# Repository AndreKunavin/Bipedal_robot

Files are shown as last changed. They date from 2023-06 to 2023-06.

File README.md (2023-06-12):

# Бипедальный робот

Проект по курсу "Проектирование, прототипирование и производство в проектном формате"

Данная работа посвящена построению двуногого робота, способного удерживать равновесие и шагать. Проект несёт образовательный характер для нашей команды: понимание проблем, возникающих при разработке подобных устройств, а также самостоятельное их решение - цель нашего проекта.

Описание проекта можно посмотреть в файле "bipedal.pdf"	

## Технические заметки и исходные файлы для печати
В папке STL&SLDPTR находятся файлы с 3D моделями основных компонент робота. Далее приведено их краткое описание. 

С целью упрощения управления прототипами, а также более эффективного распределения сил команды, было решено разделить проект на две части: 
### 1) Разработка "активного" голеностопа
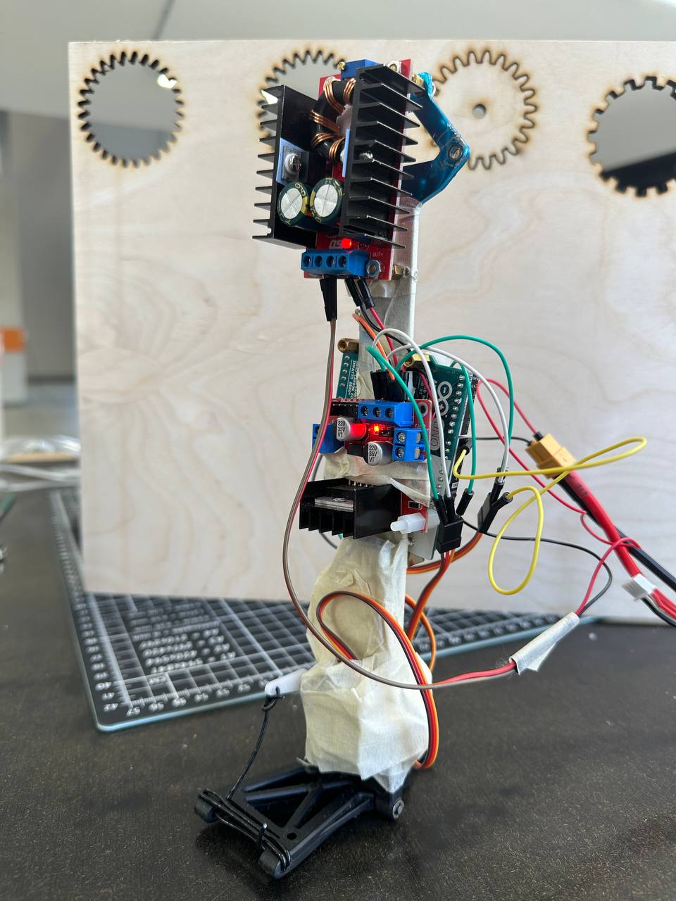
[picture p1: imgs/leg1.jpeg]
Голеностоп


Гироскоп, установленный свехру, реагирует на внешнее механическое воздействие и подает сигнал на стопу, которая пытается скомпенсировать воздействие.
  
### 2) Разработка основной механической конструкции робота
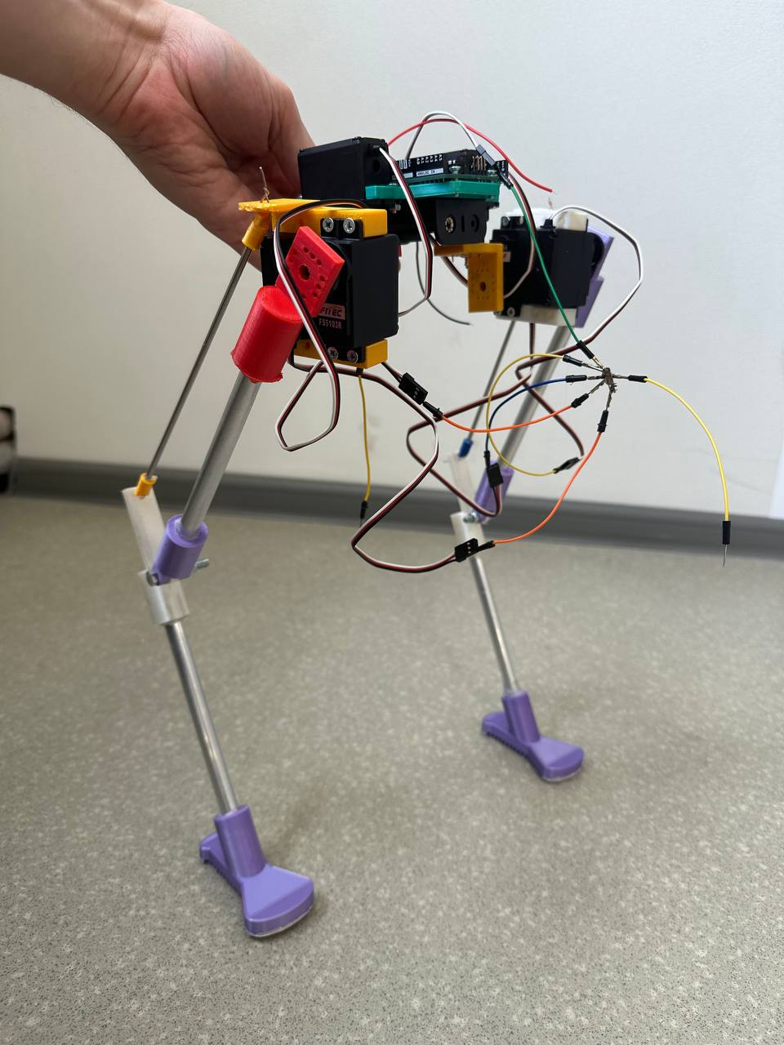
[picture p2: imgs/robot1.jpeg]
Основная механическая часть
 

1. БлокСерво.STL и БлокСерво2.STL - крепление двух сервоприводов к платформе с Arduino. Один из сервоприводов отвечает за поднятие стопы (меняет относительное положение верхней трубки и спицы), а второй - за вынос ноги вперед как целого.
2. ВерхнееКрепление.STL, Нижнее крепление.STL - крепления, соединяющие нижнюю и верхнюю трубки. Нижнее крепление имеет рычаг, к которому крепится спица
3. НогаПривод.STL - соединение верхней трубки ноги и сервопривода, отвечающего за поднятие стопы
4. Стопа.STL - "пассивная" стопа, временная альтернатива вышеописанной стопе
5. КреплениеДляПлаты.STL - крепление, на котором размещается "мозг" робота - Arduino Uno

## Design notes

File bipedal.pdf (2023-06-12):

Министерство образования и науки Российской Федерации Московский физико-технический институт (национальный исследовательский университет)

Физтех-школа Радиотехники и Компьютерных Технологий (ФРКТ) Дисциплина «Проектирование, прототипирование и производство в проектном формате»

ПОЯСНИТЕЛЬНАЯ ЗАПИСКА К КУРСОВОМУ ПРОЕКТУ «БИПЕДАЛЬНЫЙ РОБОТ»

Выполнили:
Бексултанова Айкун, Б01-906

Кофанов Даниил, Б01-909

Кунавин Андрей, Б01-903

Фёдоров Михаил, Б01-905

Долгопрудный, 2023

### 1. Разработчики

- Бексултанова Айкун: обзор статей, печать деталей, подготовка презентации, сборка.
- Кофанов Даниил: прототипирование активного голеностопа, CAD-моделирование монтажной платформы.
- Кунавин Андрей: обработка деталей после печати, сборка.
- Фёдоров Михаил: CAD-моделирование конечностей, сборка

### 2. Цель работы

Осуществить попытку в построении двуногого робота в ограниченном бюджете, способного удерживать равновесие и шагать, понять проблемы возникающие при разработке подобных устройств и попытаться решить их самостоятельно. В виду этого, данный проект разрабатывался со стремлением к минимизации заимствования из уже существующих решений.

Основной идеей нашей модели является разделение механических узлов на две части, одна из которых ответственна только за удержание/вывод из положения равновесия, а другая служит для непосредственного выноса/возвращения конечности при шаге. Такая модель должна упростить разработку в силу минимизации интерференции в управлении этими механическими узлами, позволяя разбить это управление на 2 сабрутины. В виду этого, разработка разделилась на 2 соответствующих подпроекта.

A. Модель продольной устойчивости.

Достижение устойчивости достигается за счёт управления стопой (см. Рисунок 1). В момент выхода из положения равновесия (т.е. детектирования гироскопом ускорения) модель стремится нивелировать внешнее воздействие с помощью сервоприводов, создавая компенсирующий момент.

Стоит отметить, что отдельное изготовление этого устройства было необходимо для

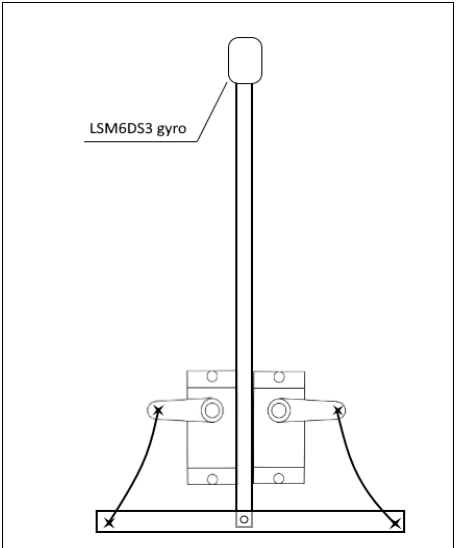
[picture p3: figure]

проверки самой идеи удержания равновесия с помощью лишь стопы (т.е. при неизменной геометрии остальной части). В конечной имплементации система управления и питания так же бы были вынесены в общий корпус, поэтому внешнему виду, качеству исполнения и монтажу уделялось мало внимания.

Рисунок 1: Схема модуля устойчивости

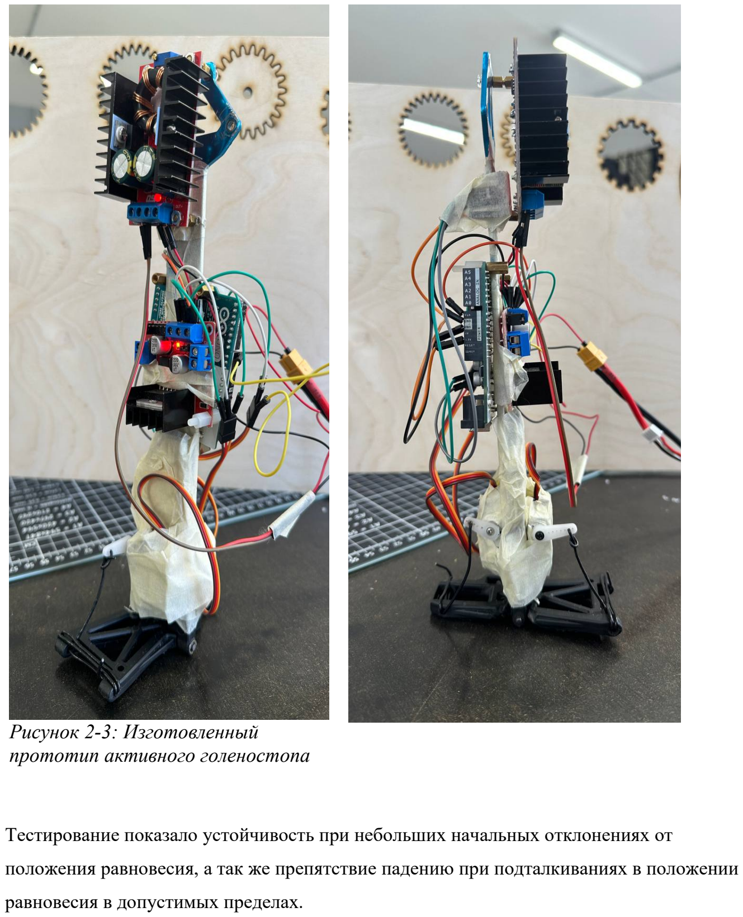
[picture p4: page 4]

Тестирование показало устойчивость при небольших начальных отклонениях от положения равновесия, а так же препятствие падению при подталкиваниях в положении равновесия в допустимых пределах.

Рисунок 2-3: Изготовленный
прототип активного голеностопа

B. Основная механическая часть

Основная механическая часть (см. Рисунок 4) управляется 6 сервоприводами, по 3 на каждую конечность. В каждой ноге, 2 сервопривода обеспечивают поворот ноги относительно корпуса в вертикальной плоскости, необходимого для осуществления шага, и горизонтальной плоскости, необходимого для поворота. Третий сервопривод воздействуя на рычаг обеспечивает сгибание ноги, что необходимо для управления высотой робота и обеспечения меньшего углового момента относительно стопы, что позволяет активному голеностопу лучше справляться с удержанием равновесия.

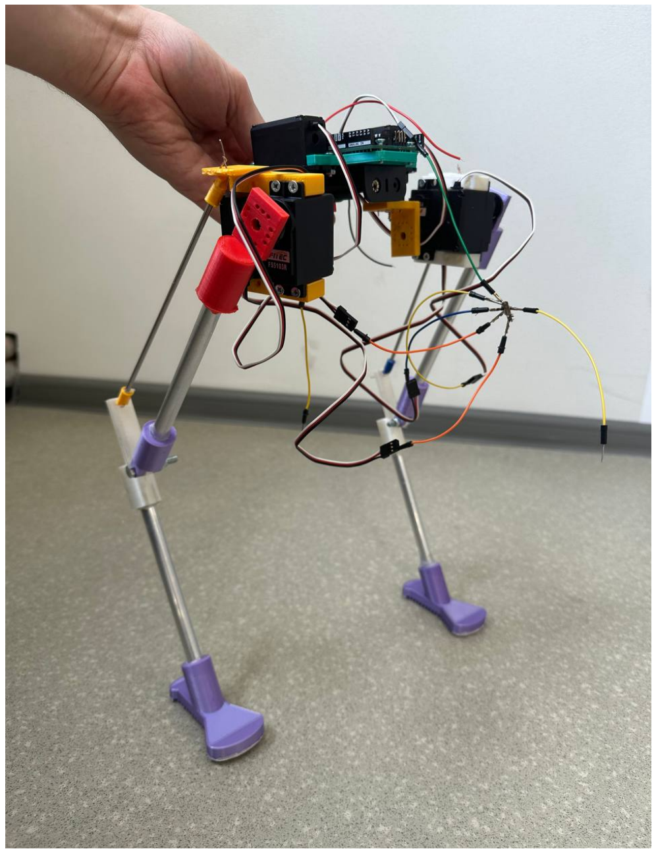
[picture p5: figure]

Рисунок 4: Основная механическая часть

В данной реализации стопа является монолитной. Предполагается, что после обеспечения робота адекватной системой питания и базового управления сервоприводами (хотя бы обеспечения статического положения), следует заменить её на подвижную стопу, аналогичную изображённой на Рисунке 1 и крепящуюся на стержень голени, гироскоп же установить в верхней точке робота.

### 3. Обзор существующих аналогов

Наиболее близким к данному проекту является робот описанный в статье https://www.mdpi.com/2076-0825/11/3/75/htm. Одним из главных отличий является использования в нём особых бесколлекторных двигателей, в то время как мы используем более дешёвые и общие сервоприводы. Принципиально что сервоприводы качественно отличаются от двигателей в том смысле что двигатели могут свободно вращаться под действием внешних сил, в то время как сервопривод всегда стремится удержать определённое положение. Это создаёт трудности при жёстком соединении сервоприводов со стопой в момент постановки стопы в процессе переступания. В виду этого в нашей реализации стопа соединяется с сервоприводами не стержнем, а тросом, допуская тем самым «расслабление» (т.е. свободное позиционирование) стопы при необходимости.

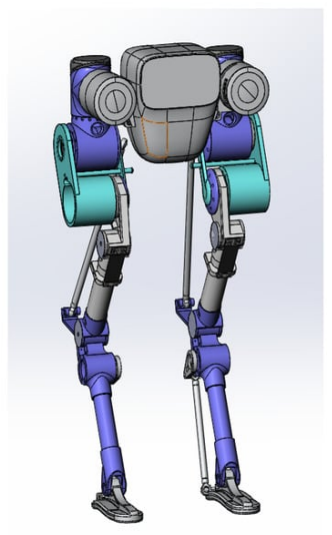
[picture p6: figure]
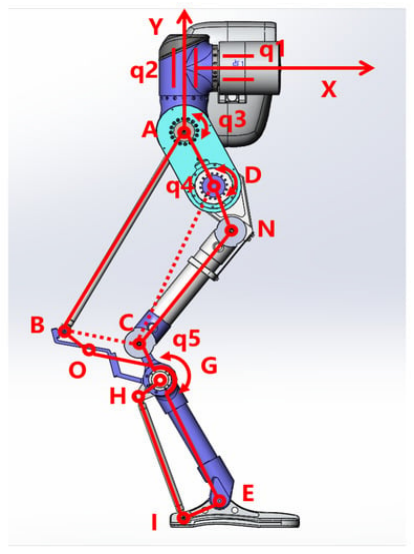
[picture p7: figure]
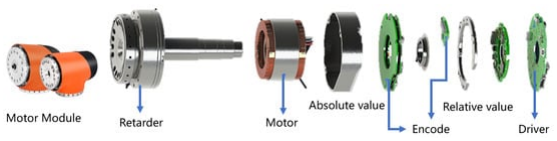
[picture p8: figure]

Рисунок 7: Составные части двигателя робота из статьи

Рисунок 5-6: 3D модель
робота из статьи

### 4. Процесс проектирования и изготовления

Проектирование состояло из следующих шагов:
1) Обзор уже существующих роботов и выбор механической модели;
2) Подбор необходимых электронных компонентов (гироскопа, плат управления питанием, сервоприводы и т.д.);
3) Прототипирование и тестирование активного голеностопа.
4) Проектирование и изготовление механической части;
5) Сборка механической части, подключение электронных компонент;
6) Интеграция активного голеностопа в основную механическую часть;
7) Обеспечение устойчивости путём калибровки и отладки параметров (границ ускорений для начала управления сервоприводами, скорости поворота сервоприводов и т. д.);
8) Имплементация механизма шагания путём контролируемого выхода из положения равновесия, выставления одной из ног вперёд и возвращения в исходное положение.

### 5. Достигнутые результаты и предстоящие цели

К сожалению, полностью работу выполнить не удалось, был достигнут только 5 пункт. В дальнейшей работе помимо перечисленных выше пунктов 6-8 остаётся открытым вопрос поперечной устойчивости в момент удержания равновесия на одной стопе. Одним из возможных решений (помимо продолжения ширины стопы до центра тяжести) является добавление в стопу степени свободы и организация механизма аналогичного механизму удержания продольного равновесия.

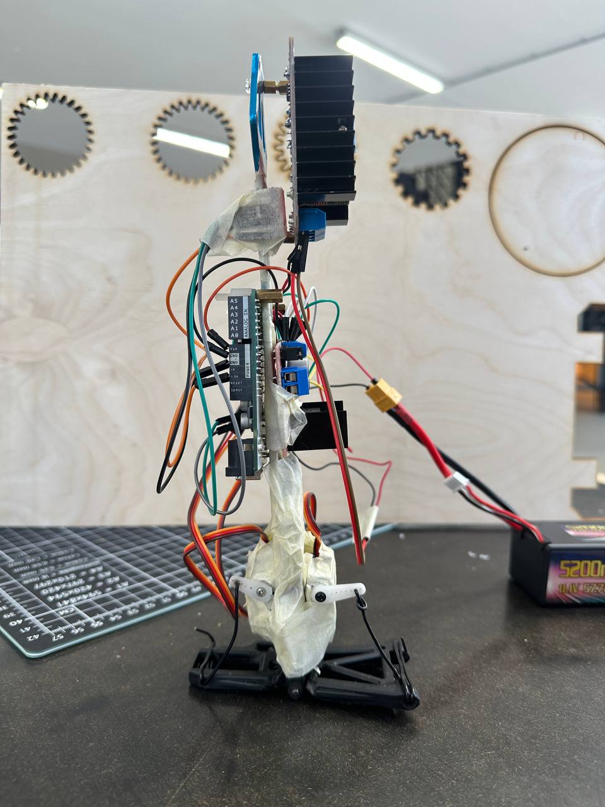
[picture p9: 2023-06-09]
imgs/leg3.jpeg

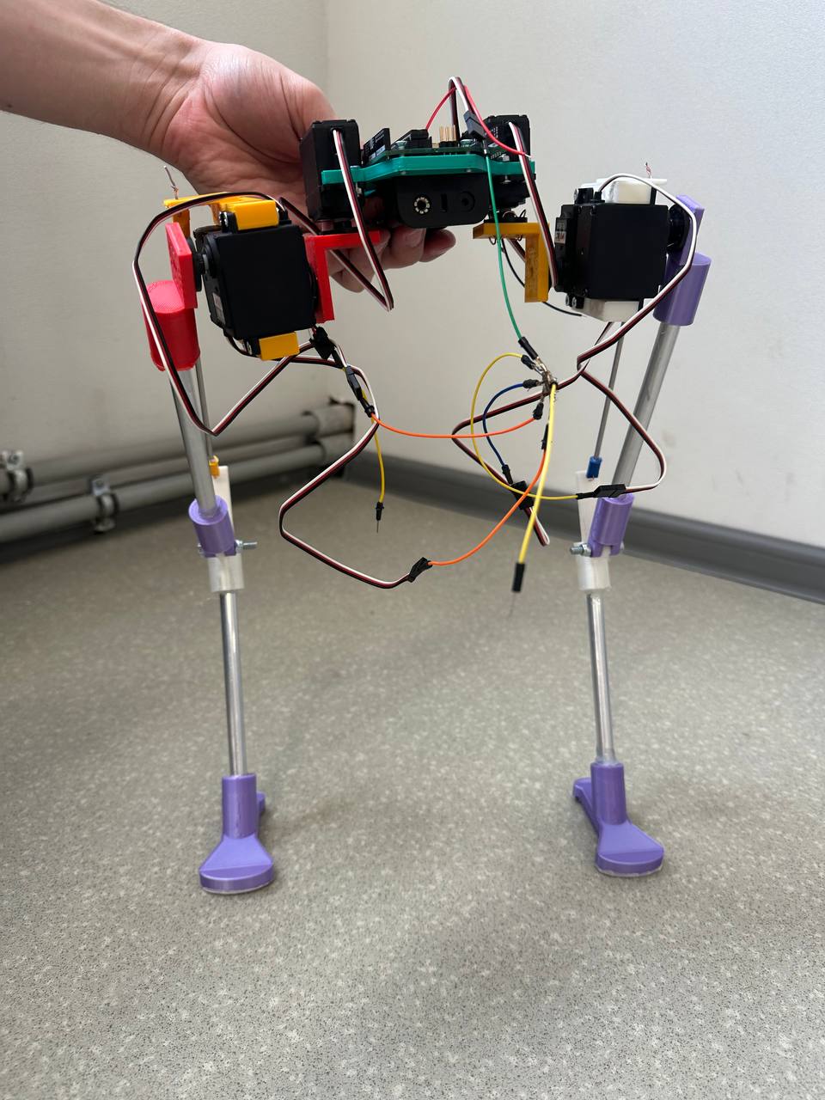
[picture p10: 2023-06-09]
imgs/robot2.jpeg

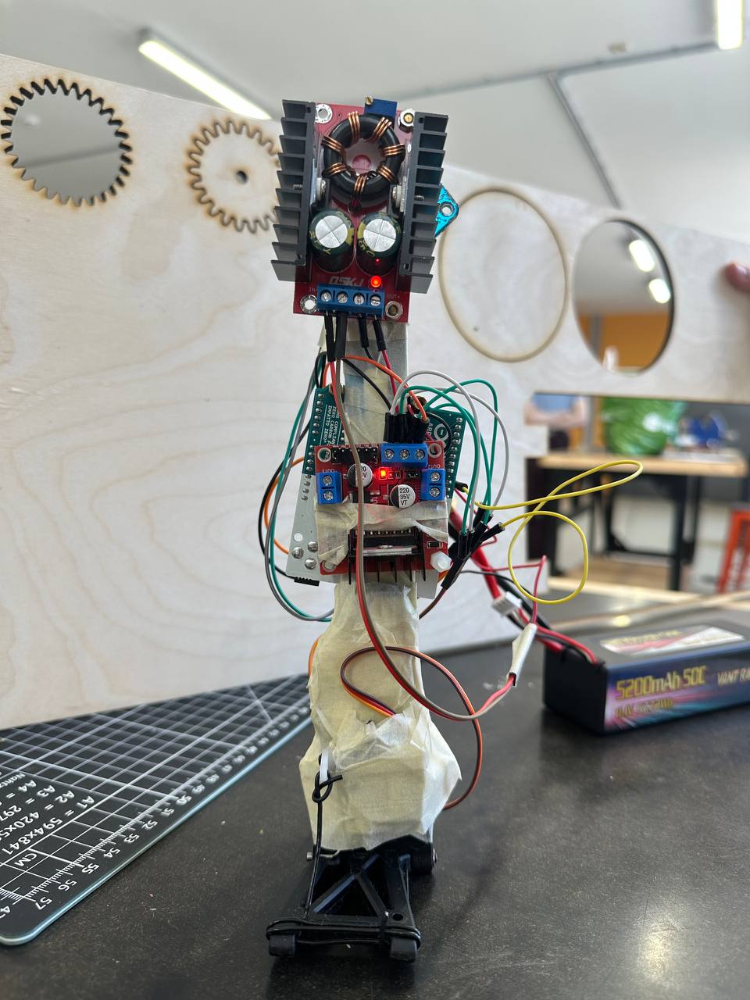
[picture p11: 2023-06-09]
imgs/leg2.jpeg

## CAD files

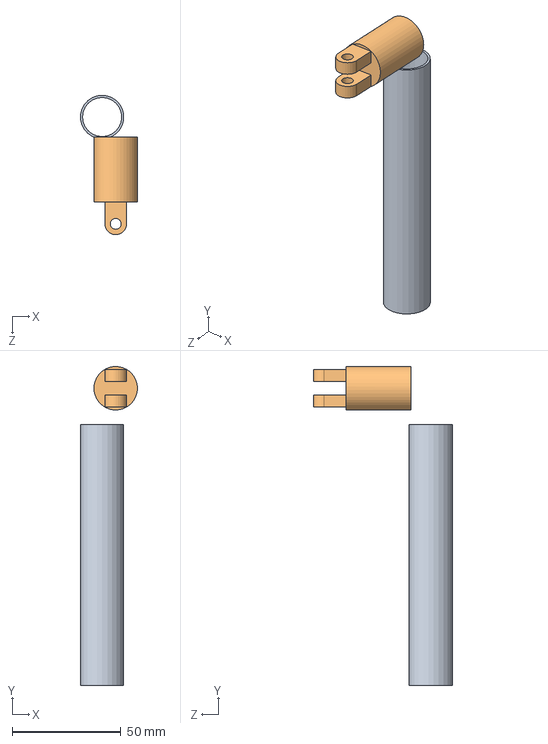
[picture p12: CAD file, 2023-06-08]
STL&SLDPRT/РобоногаSLDASM.SLDASM
26.2 x 146.6 x 64.1 mm
Трубка
ВерхнееКрепление

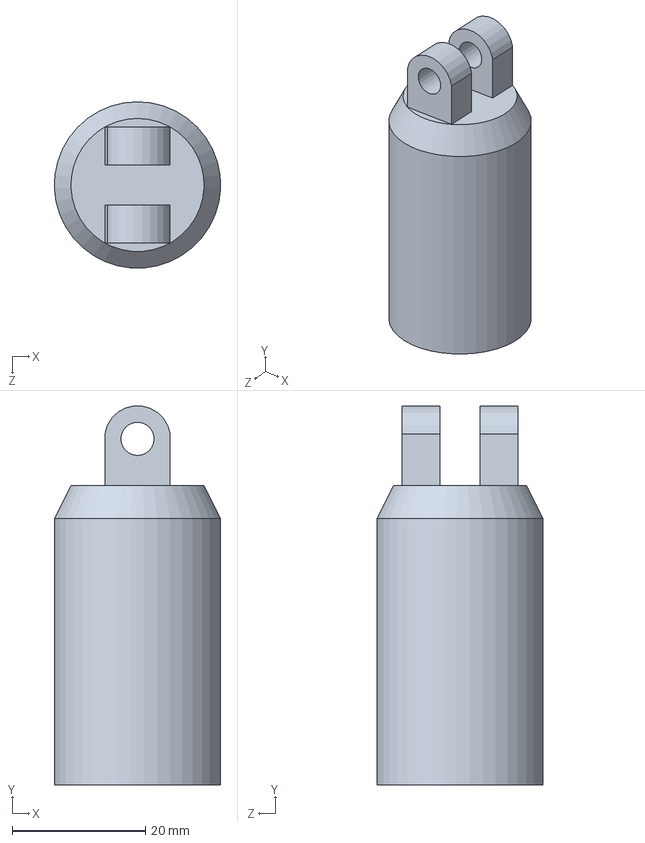
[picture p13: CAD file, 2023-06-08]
STL&SLDPRT/Верхнее крепление.SLDPRT
25.0 x 56.9 x 25.0 mm

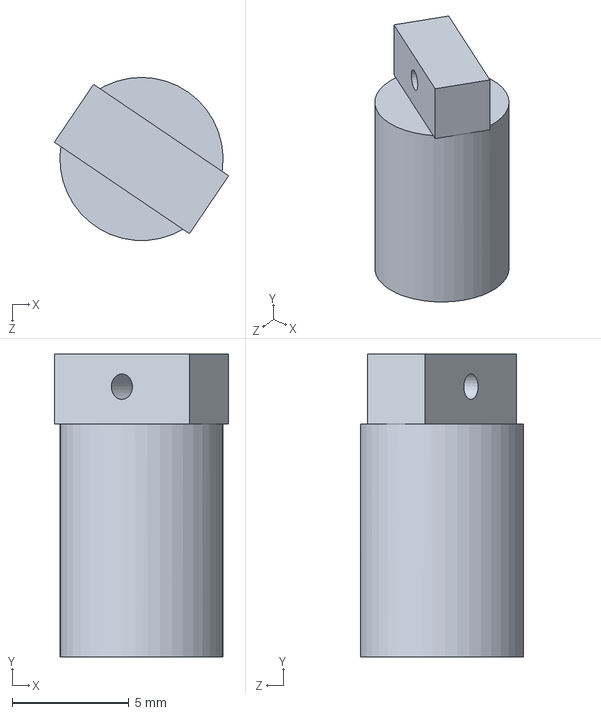
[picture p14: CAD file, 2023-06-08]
STL&SLDPRT/Спица.SLDPRT
7.48 x 13.0 x 7.00 mm

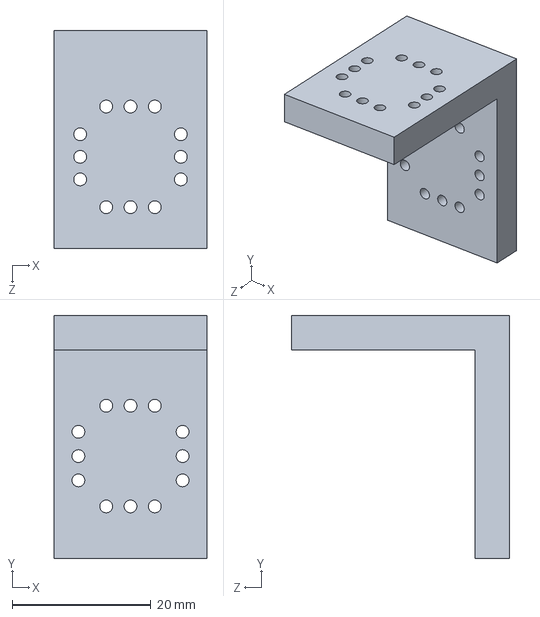
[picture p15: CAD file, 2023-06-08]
STL&SLDPRT/СервоСерво.SLDPRT
22.0 x 35.0 x 31.4 mm

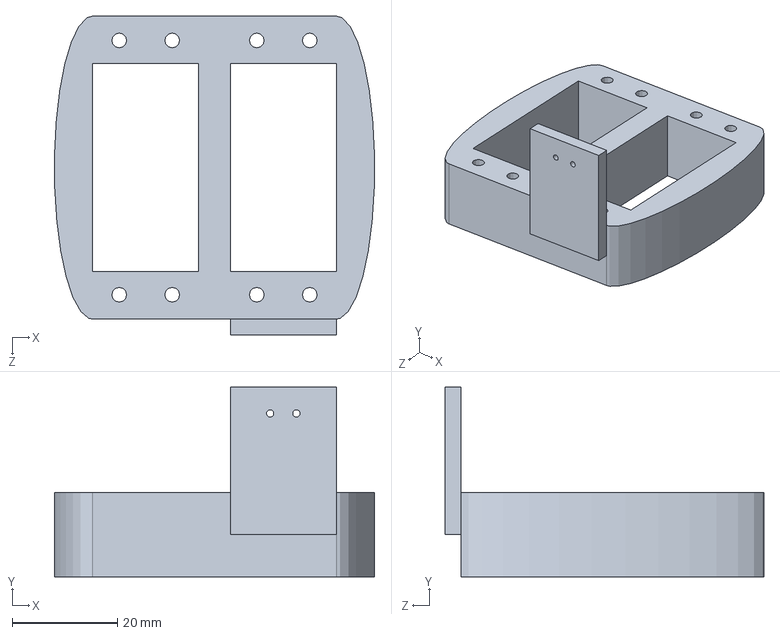
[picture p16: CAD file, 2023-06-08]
STL&SLDPRT/БлокСерво2.SLDPRT
60.7 x 36.0 x 60.5 mm

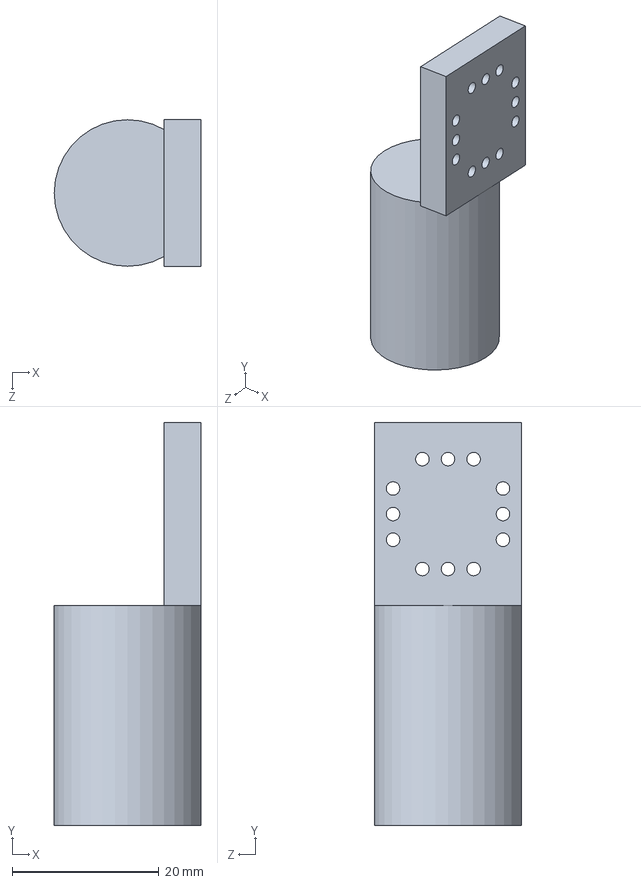
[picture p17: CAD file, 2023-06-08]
STL&SLDPRT/НогаПривод.SLDPRT
20.0 x 55.0 x 20.0 mm

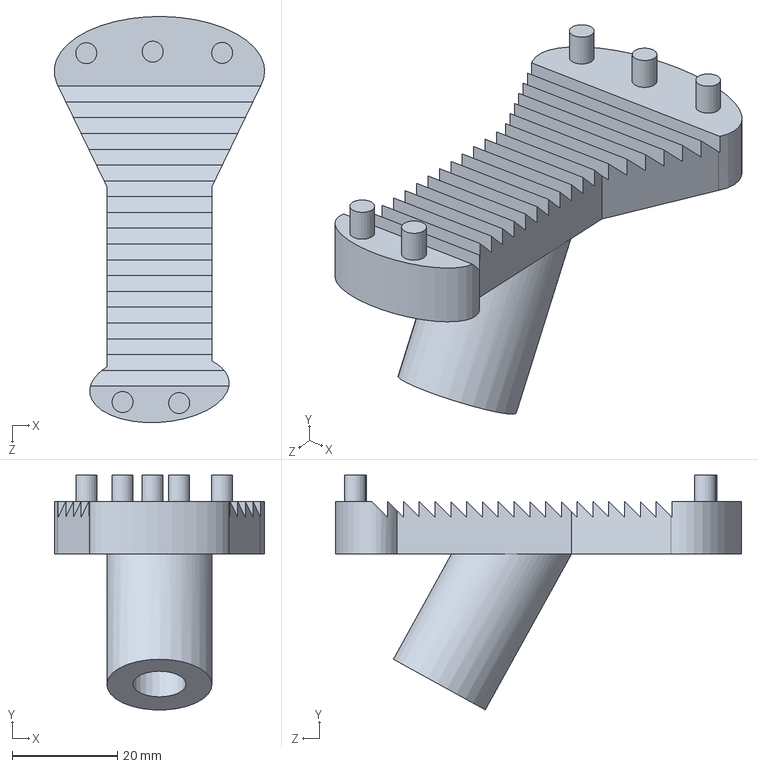
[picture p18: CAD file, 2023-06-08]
STL&SLDPRT/Стопа.SLDPRT
40.0 x 44.6 x 77.1 mm

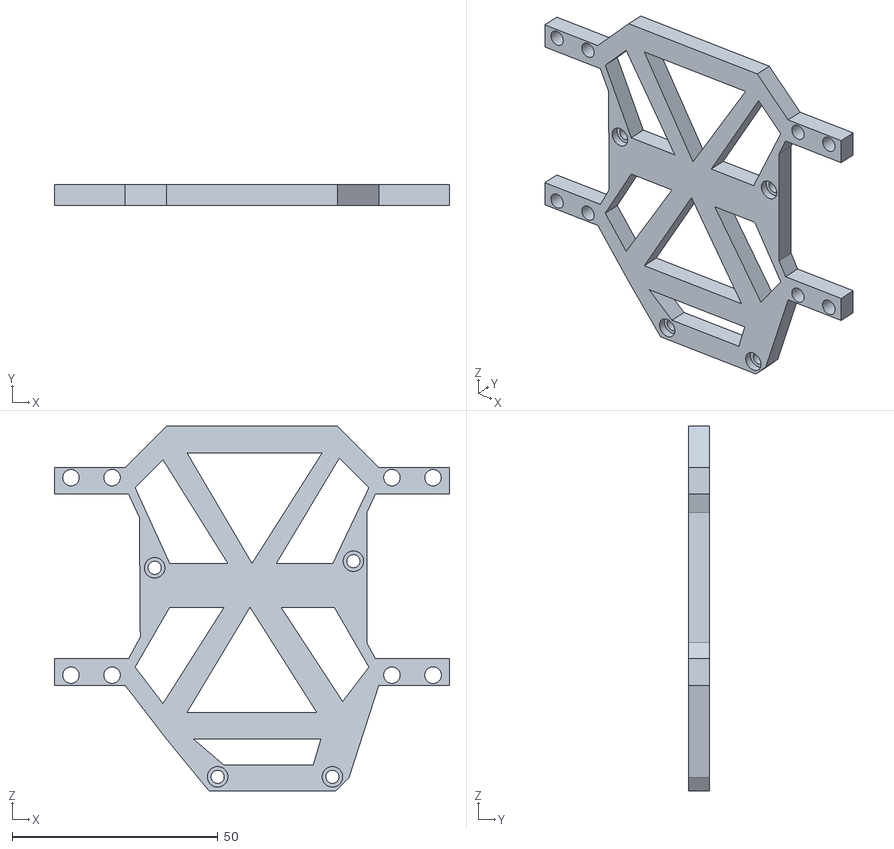
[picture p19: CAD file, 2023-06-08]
STL&SLDPRT/КреплениеДляПлаты.STL
96.0 x 5.00 x 88.6

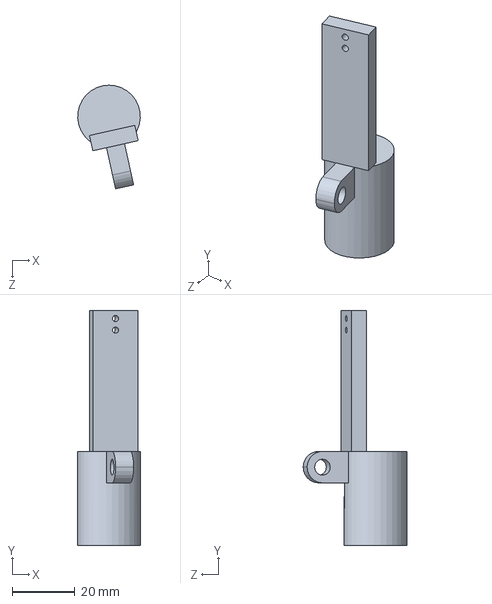
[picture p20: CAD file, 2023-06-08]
STL&SLDPRT/Нижнее крепление.SLDPRT
20.0 x 75.0 x 33.1 mm

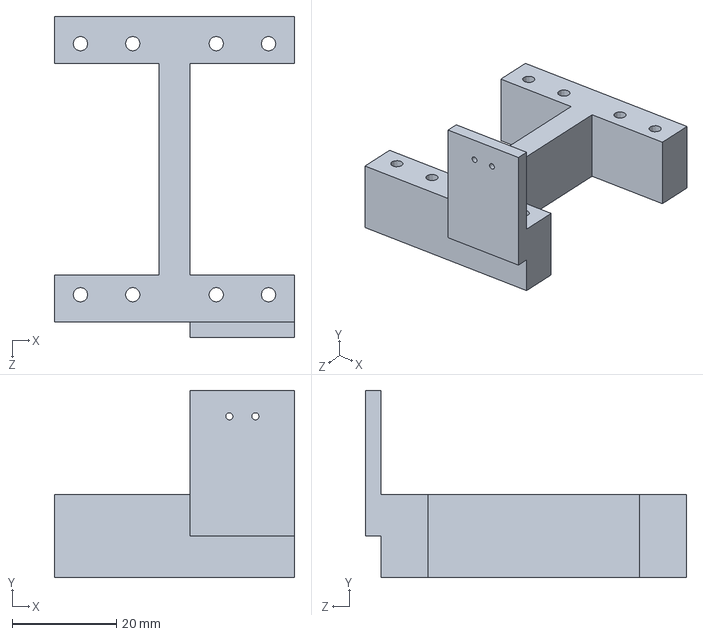
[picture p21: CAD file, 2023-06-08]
STL&SLDPRT/БлокСерво.SLDPRT
46.2 x 36.0 x 61.7 mm

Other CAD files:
STL&SLDPRT/Деталь1.SLDPRT
STL&SLDPRT/Деталь2.SLDPRT
STL&SLDPRT/БлокСерво.STL
STL&SLDPRT/БлокСерво2.STL
STL&SLDPRT/ВерхнееКрепление.SLDPRT
STL&SLDPRT/ВерхнееКрепление.STL
STL&SLDPRT/Нижнее крепление.STL
STL&SLDPRT/НогаПривод.STL
STL&SLDPRT/Спица.STL
STL&SLDPRT/Стопа.STL
